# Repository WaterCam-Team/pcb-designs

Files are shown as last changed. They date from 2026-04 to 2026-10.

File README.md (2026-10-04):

# SU WaterCam PCB

Custom KiCad HAT for the **SU-WaterCam** project. Stacks on a Raspberry Pi 4B via a WittyPi 4 RTC/power-manager board, adding thermal imaging, LoRaWAN telemetry, IMU orientation, and environmental sensing.

**Software repo:** [mandeeps/SU-WaterCam](https://github.com/mandeeps/SU-WaterCam)  
**Schematic/pin map:** [PIN_MAP.md](PIN_MAP.md)

---

## Stack Order

Raspberry Pi 4B → WittyPi 4 (stacking header) → WaterCam HAT

---

## Components

| Reference | Part | Interface | Notes |
|---|---|---|---|
| U2 | Adafruit BNO055 STEMMA QT | I2C1 (0x28) | 9-DOF IMU; INT→GPIO20, RST→GPIO16 |
| U3 | Multitech MTDOT-915 | UART5 (GPIO12/13) | LoRaWAN; always-on 3.3 V from WittyPi J3 |
| U1 | Adafruit AHT20 | I2C1 (0x38) | Temp/humidity |
| J2 | FLIR Lepton Breakout v2 | SPI0 + I2C1 | 2×10 header; SPI for image data, I2C for CCI |
| J3 | WittyPi 4 P3 header | — | Taps always-on 3.3 V and SW pin for mDot |
| Q1 | MOSFET | — | mDot PB_1 pulls WittyPi SW low for remote wake |

---

## Power Domains

| Rail | Source | Powers |
|---|---|---|
| +3V3 (Pi) | Pi J1 pin 1 | AHT20, BNO055 breakout, I2C pull-ups R6/R7 |
| 5 V (Pi) | Pi J1 pin 2/4 | FLIR Lepton VIN (J2-P2) |
| 3.3 V (always-on) | WittyPi J3 pin 2 | mDot VDD, mDot NRESET pull-up — survives Pi shutdown |

---

## PCB Details

- **Layers:** 2 (F.Cu, B.Cu)
- **Signal traces:** 0.25 mm
- **Power traces:** 0.5 mm
- **Clearance:** 0.20 mm (default net class)

---

## PCB Images

- **Wiring/Layout Diagram**  
  Wiring/Layout Diagram of SU-WaterCam PCB

- **PCB Render**  
  3D Render of SU-WaterCam PCB

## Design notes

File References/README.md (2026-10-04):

# Reference documents

The design was checked against these vendor documents. They aren't committed
here because they are the vendors' copyright; download them from the vendor:

| Document | Source |
|---|---|
| AHT20 data sheet | Aosong (ASAIR) |
| Adafruit AHT20 temperature & humidity breakout guide | Adafruit Learning System |
| Adafruit 9-DOF orientation IMU fusion breakout (BNO085) guide | Adafruit Learning System |
| FLIR Lepton Breakout Board v2 schematic | GroupGets / Teledyne FLIR |
| Lepton Integration Series 302: SPI and I2C protocols | Teledyne FLIR |
| Lepton adaptor schematic | Teledyne FLIR |
| Quick start guide: Lepton and Raspberry Pi | GroupGets |
| IRLB8721PbF MOSFET data sheet | Infineon (International Rectifier) |
| Quectel EC25/EC21 GNSS AT commands manual v1.1 | Quectel |
| Witty Pi 4 user manual | UUGear |
| MultiTech mDot developer guide (S000612) | MultiTech |

`wiring_diagram.svg` in this folder is our own.

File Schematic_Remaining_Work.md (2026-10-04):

# WaterCam HAT — Schematic Remaining Work

**Board:** WaterCam_mDot_WittyPi_AHT_BNO_Lepton  
**Schematic:** `WaterCam_mDot_WittyPi_AHT_BNO_Lepton.kicad_sch` (KiCad 9)  
**Prepared:** 2026-05-10  
**Scope:** Schematic-only fixes. PCB layout work tracked separately.

---

## Status Summary

| # | Issue | Schematic Fix | Status |
|---|---|---|---|
| 7 | EEPROM artifacts (labels + wires) | Remove ID_SDA/ID_SCL labels and wires | ✅ Done |
| 9 | No I2C pull-up resistors | Add R6, R7 (4.7 kΩ each) | ✅ Done |
| 11 | Q1 MOSFET oversized (IRLB8721 TO-252) | Swap to 2N7002 SOT-23 | ✅ Done |
| 14 | Q1 gate resistor missing | Add R8 (100 Ω) in gate net | ✅ Done |
| 16 | mDot NRESET unconnected | Add 10 kΩ pull-up to 3.3 V | ✅ Done |
| 17 | J2-P18 PW_DWN_L not tied | Verify +3V3 tie; add if missing | ✅ Done |
| 8/15 | Decoupling caps missing | Add C1–C6 (100µF/100nF/10µF) | ✅ Done |
| ERC | +3V3 net power flag | Add #FLG04 (PWR_FLAG) on +3V3 | ✅ Done |

Issues #1–6, #10, #12, #13 are either fixed, N/A, or PCB-layout-only.

**Schematic complete. All issues resolved. Ready for ERC + PCB update.**

---

## Issue #7 — Remove EEPROM Artifacts

**Background:** U4 (CAT24C256 EEPROM) was added in an earlier session then deemed unnecessary (overlays loaded via config.txt). U4 was removed from the schematic but the schematic still has dangling ID_SDA/ID_SCL net labels and their connecting wires at J1 GPIO0 (Pi pin 27) and GPIO1 (Pi pin 28). These conflict with the no_connect marks already placed at the same points, causing ERC errors.

**Elements to remove:**
| Element | Location | Action |
|---|---|---|
| Label `ID_SDA` | (31.75, 60.96, 0°) | Delete |
| Label `ID_SCL` | (100.33, 60.96, 180°) | Delete |
| Wire J1-GPIO0 → label | (60.96, 60.96) → (31.75, 60.96) | Delete |
| Wire J1-GPIO1 → label | (73.66, 60.96) → (100.33, 60.96) | Delete |
| `no_connect` at label end | (31.75, 60.96) UUID `41ad66df-...` | Delete |
| `no_connect` at label end | (100.33, 60.96) UUID `bb504bb4-...` | Delete |

**Elements to add:**
| Element | Location | Reason |
|---|---|---|
| `no_connect` | (60.96, 60.96) | Mark J1 pin 27 (GPIO0/ID_SDA) as intentionally NC |
| `no_connect` | (73.66, 60.96) | Mark J1 pin 28 (GPIO1/ID_SCL) as intentionally NC |

**Verification:** After edit, ERC should show no error for J1 pins 27/28. Both should appear as clean no-connects in the netlist.

---

## Issue #9 — I2C Pull-Up Resistors (R6, R7)

**Background:** The I2C1 bus (GPIO2/SDA1, GPIO3/SCL1) has no board-level pull-ups. The Adafruit AHT20 and BNO055 breakout boards include their own 10 kΩ pull-ups, but having multiple boards in parallel on a shared bus weakens the effective pull-up strength. The Lepton CCI interface (I2C at 0x2A) requires pull-ups to be present. Adding 4.7 kΩ on the HAT provides a stable bus regardless of which breakouts are populated.

**Design:**
- R6: 4.7 kΩ, 0402, from GPIO2/SDA1 to +3.3 V
- R7: 4.7 kΩ, 0402, from GPIO3/SCL1 to +3.3 V

**Schematic approach:** Place R6 and R7 as vertical stubs branching off the SDA1 and SCL1 wires near J1. Each resistor connects between the signal net (via net label or T-junction on the existing wire) and a `power:+3V3` power symbol.

**Placement strategy:**
- Locate the SDA1 wire (y ≈ 30.48) and SCL1 wire (y ≈ 33.02) to the left of J1
- Add a junction on each wire at a free x-coordinate (e.g., x ≈ 20.32)
- Run a short vertical wire stub upward from each junction
- Place R6 / R7 vertically (90°) above the junction
- Connect top pin of each resistor to a `power:+3V3` symbol

**Net labels:** SDA1 net = `GPIO2{slash}SDA1`, SCL1 net = `GPIO3{slash}SCL1`

**New component definitions:**
```
R6: lib_id = Device:R_Small, value = "4.7kΩ", footprint = Resistor_SMD:R_0402_1005Metric
R7: lib_id = Device:R_Small, value = "4.7kΩ", footprint = Resistor_SMD:R_0402_1005Metric
```

**Note on +3.3 V source:** The Pi's 3.3 V rail appears at J1 pins 1 and 17 but is currently no-connect in the schematic (the HAT draws 3.3 V from the Pi only via breakout boards' own regulators). To add I2C pull-ups, add `power:+3V3` symbols connected directly to the J1 pin 1 (60.96, 27.94) and route pin 1 to a +3V3 power net. This also resolves the inconsistency where J1 pin 1 is no_connect while the schematic claims 3.3 V powers the breakouts.

**Alternative (simpler):** If the +3V3 net conflict is undesirable, use the `power:+5V` net and add a dedicated 3.3 V LDO (Issue #18) — but this is out of scope for schematic-only work. Use `power:+3V3` for now; verify J1 pin 1 drives it.

---

## Issue #11 — Q1 MOSFET Replacement (IRLB8721 → 2N7002)

**Background:** Q1 is an IRLB8721PBF (30 V / 62 A, TO-252 package) used as a small-signal switch to pull the WittyPi SW line LOW when the mDot asserts PB_1. This is severe overkill. The correct device is a 2N7002 (60 V / 300 mA, SOT-23) or BSS138.

**Gate drive:** mDot PB_1 = 3.3 V logic. Both 2N7002 (Vgs(th) ≈ 1.0–2.5 V) and BSS138 (Vgs(th) ≈ 0.8–1.5 V) fully saturate with 3.3 V gate drive.

**Schematic changes (properties only — no rewiring):**
| Property | Current | New |
|---|---|-----|
| `lib_id` | `Simulation_SPICE:NMOS` | `Transistor_FET:2N7002` |
| `Value` | `NMOS` | `2N7002` |
| `Footprint` | `IRLB8721PBF Model:TO254P1067X483X2057-3` | `Package_TO_SOT_SMD:SOT-23` |
| `Datasheet` | ngspice URL | `https://www.vishay.com/docs/70226/70226.pdf` |

**Pin mapping for 2N7002 in SOT-23:**
- Pin 1 = Gate (G)
- Pin 2 = Source (S)  
- Pin 3 = Drain (D)

**Note:** The `Transistor_FET:2N7002` KiCad symbol uses pin names G/D/S. Verify the lib_symbol pin orientation matches the existing wiring before saving. If the pin mapping differs from the current NMOS simulation symbol, the drain/source/gate connections must be reconciled.

**Alternative:** Keep the `Simulation_SPICE:NMOS` schematic symbol (generic N-MOSFET) and only update the footprint and value. This avoids a pin-mapping conflict. A BOM note can specify 2N7002/BSS138.

---

## Issue #14 — Q1 Gate Resistor (R8, 100 Ω)

**Background:** mDot PB_1 drives Q1 gate directly with only a 10 kΩ pull-down (R3). No series gate resistor exists. At 3.3 V / 10 kΩ, gate current is 330 µA, which is fine for steady state. The concern is ringing at turn-on/off: the LoRa module's GPIO transitions can excite the gate-source capacitance (Ciss ≈ 50–100 pF for 2N7002) causing ringing on the gate that may cause spurious switching.

**Fix:** Add R8 = 100 Ω in series between the mDot PB_1 signal and Q1 gate. The R3 10 kΩ pull-down remains connected at the Q1 gate side (after R8), which is correct — it provides DC bias when mDot is unpowered.

**Circuit topology:**
```
mDot PB_1 ── R8 (100Ω) ─┬─ Q1 Gate
                          │
                         R3 (10kΩ)
                          │
                         GND
```

**Schematic changes:**
1. Identify the gate wire segment (the wire running at y ≈ 172.72 from Q1 gate toward the mDot PB_1 side)
2. Break this wire at a point approximately 10–15 mm from Q1 gate (to leave room for R8 symbol)
3. Add R8 (`Device:R_Small`, value `100Ω`, footprint `Resistor_SMD:R_0402_1005Metric`) in the gap, oriented horizontally (0°)
4. Connect R8 pin 1 to the mDot-PB_1-side wire stub
5. Connect R8 pin 2 to the Q1 gate-side wire stub

**R3 stays:** The existing R3 (10 kΩ at position ~177.8, 161.29, vertical) is the gate pull-down. Its connection to the Q1 gate net is correct and unchanged.

---

## Issue #16 — mDot NRESET Pull-Up

**Background:** mDot NRESET (active-low, pin 5 of U3) is currently no_connect at (243.84, 81.28). Leaving NRESET floating can cause spurious resets if the line picks up noise. The mDot datasheet recommends tying NRESET HIGH via a 10 kΩ resistor to VDD (3.3 V) with an optional 100 nF capacitor to GND.

**Fix:** Add R9 = 10 kΩ pull-up from NRESET to 3.3 V (WittyPi always-on 3.3 V, same supply as mDot VDD).

**Schematic changes:**
1. Remove `no_connect` at (243.84, 81.28)
2. Add a short wire stub from (243.84, 81.28) going LEFT (decreasing x) to approximately (234.95, 81.28)
3. Place R9 (`Device:R_Small`, value `10kΩ`, footprint `Resistor_SMD:R_0402_1005Metric`) horizontally (0°) with pin 1 at (234.95, 81.28)
4. Add a wire from R9 pin 2 (left side) going left to approximately (228.6, 81.28)
5. Add a `power:+3V3` symbol at the end OR use the WittyPi J3-3V3 label to connect to the always-on 3.3 V supply

**Power domain note:** mDot VDD is already on WittyPi J3-3V3 (always-on). NRESET must also be on this rail — if tied to Pi 3.3 V (which goes off when WittyPi shuts the Pi), NRESET would assert LOW during Pi shutdown and hold the mDot in reset. Use WittyPi J3-3V3 for this pull-up.

**Schematic label:** The J3-3V3 wire chain already exists. Connect R9 top to the same net using a `power:+3V3` symbol OR a local wire to J3 pin 2 (at (231.14, 35.56)).

---

## Issue #17 — J2-P18 PW_DWN_L Verification

**Background:** Fix 5 was supposed to tie J2-P18 (Lepton PW_DWN_L) to +3.3 V so the Lepton is always powered. Verify this fix is actually present in the current schematic.

**Check:**
- J2-P18 position: even pin at (121.92, 128.27)
- Expected: wire from (121.92, 128.27) to a `power:+3V3` symbol (or at minimum, a wire to the +3V3 rail)
- Current state: `no_connect` found at (121.92, 128.27) — **Fix 5 may not be applied**

**Action:** If no_connect is the only thing at (121.92, 128.27):
1. Remove the `no_connect` at (121.92, 128.27)
2. Add a short wire from (121.92, 128.27) going LEFT to ~(113.03, 128.27)
3. Add `power:+3V3` symbol at (113.03, 128.27)
4. Add a 10 kΩ pull-up resistor between this +3V3 and the signal for cleaner design (optional; direct tie is acceptable per Issue #17 note in the main change doc)

---

## PCB Layout Work (Out of Scope for This Document)

These require the PCB editor (not the schematic):

| # | Action |
|---|---|
| 8/15 | Add decoupling caps C1–C6 (see WaterCam_PCB_Design_Changes_Required.md §8) |
| 12 | Verify stacking header J1 height (11–13 mm female socket) |
| 13 | Fix MTDOT footprint duplicate pad "24" |

All PCB changes should be deferred until schematic issues #7, #9, #11, #14, #16, #17 are resolved and the schematic passes ERC.

---

## KiCad Coordinate Reference

Key known positions in schematic space:

| Component | Position | Notes |
|---|---|---|
| J1 (Pi header) | (66.04, 50.8, 0°) | `Conn_02x20_Odd_Even`; left col x=60.96, right col x=73.66 |
| J2 (Lepton) | (129.54, 118.11, 0°, mirror y) | Even pins x=121.92, Odd pins x=134.62; y=107.95–130.81 |
| J3 (WittyPi P3) | (195.58, 57.15, 0°) | Pin 2 (3V3) at (231.14, 35.56) |
| U3 (mDot) | (274.32, 83.82, 90°, mirror x) | x_abs = 274.32 − ly_local; y_abs = 83.82 + lx_local |
| U2 (BNO055) | (153.67, 29.21, 180°) | x_abs = 153.67 − lx_local; y_abs = 29.21 + ly_local |
| Q1 (NMOS) | (82.55, 172.72, 0°) | Gate net wire runs at y=172.72 |
| R3 (10kΩ pull-down) | (177.8, 161.29, 90°) | Gate pull-down; keep in place |
| J1-GPIO0 pin | (60.96, 60.96) | Currently has wire+label "ID_SDA" (to be removed) |
| J1-GPIO1 pin | (73.66, 60.96) | Currently has wire+label "ID_SCL" (to be removed) |
| J1-GPIO2/SDA1 | (60.96, 30.48) | Wire goes left to label at (31.75, 30.48) |
| J1-GPIO3/SCL1 | (60.96, 33.02) | Wire goes left to label at (31.75, 33.02) |
| mDot NRESET | (243.84, 81.28) | Currently no_connect; add 10kΩ pull-up |
| J2-P18 PW_DWN_L | (121.92, 128.27) | Currently no_connect; should tie +3V3 |

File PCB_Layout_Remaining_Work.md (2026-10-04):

# WaterCam HAT — PCB Layout Remaining Work

**Schematic:** WaterCam_mDot_WittyPi_AHT_BNO_Lepton.kicad_sch — all schematic issues resolved  
**PCB file:** WaterCam_mDot_WittyPi_AHT_BNO_Lepton.kicad_pcb  
**Prepared:** 2026-05-10  

---

## Prerequisites Before Opening PCB Editor

1. **Run ERC** on the schematic (KiCad Schematic Editor → Inspect → Electrical Rules Checker).  
   Expected warnings:
   - `+3V3` net "Power pin not driven" — add PWR_FLAG (#FLG04) at any +3V3 node (e.g., (60.96, 27.94) alongside the +3V3 at J1 pin 1) to silence it.
   - Any remaining unconnected pin warnings from the no_connects should pass cleanly.

2. **Update PCB from Schematic** (KiCad PCB Editor → Tools → Update PCB from Schematic, or Schematic Editor → Tools → Update PCB from Schematic).  
   This syncs all schematic changes into the PCB netlist:
   - R6, R7 (new I2C pull-ups) will appear as unplaced footprints
   - R8, R9 (gate resistor + nReset pull-up) will appear if not already placed
   - Q1 footprint change (IRLB8721 TO-252 → 2N7002 SOT-23) will need re-placement
   - +3V3 power net will be defined

---

## Issue #8 / #15 — Decoupling Capacitors C1–C6

**Why:** The mDot generates LoRa TX current spikes up to 600 mA peak on a 3.3V always-on rail that also powers WittyPi's MCU/RTC. Without local bulk capacitance, these spikes propagate back onto the WittyPi P3-3V3 rail and may cause the RTC to reset or glitch. The Lepton and I2C sensors also benefit from local bypass caps.

**Schematic step first:** Add C1–C6 to the schematic before updating the PCB.

| Ref | Value | Type | Location in schematic | Purpose |
|-----|---|---|---|---|
| C1 | 100 µF, 6.3V | Electrolytic (radial or SMD) | mDot VDD (179.07, 83.82) | mDot bulk — absorbs LoRa TX spikes |
| C2 | 100 nF, 10V | Ceramic 0402 | mDot VDD (179.07, 83.82) | mDot bypass |
| C3 | 100 nF, 10V | Ceramic 0402 | AHT20 VDD (U1 pin VDD) | AHT20 bypass |
| C4 | 10 µF, 10V | Ceramic 0402 or 0603 | AHT20 VDD | AHT20 bulk |
| C5 | 100 nF, 10V | Ceramic 0402 | BNO055 VIN (U2 pin VDD) | BNO055 bypass |
| C6 | 100 nF, 10V | Ceramic 0402 | J2-P2 (Lepton VIN) | Lepton bypass |

**Schematic additions for each cap:**
- `lib_id`: `Device:C_Small` (0402 ceramic) or `Device:C` (electrolytic C1)
- Value and footprint per table above
- One pin to the relevant VDD net (via junction on existing wire or net label)
- Other pin to `power:GND`

**PCB placement rules:**
- C1 (100 µF bulk): within 8 mm of mDot U3 VDD pad (castellated pad on mDot left edge)
- C2 (100 nF bypass): within 3 mm of mDot U3 VDD pad, closer than C1
- C3, C4: within 5 mm of U1 (AHT20) VDD pin
- C5: within 5 mm of U2 (BNO055) VIN pin
- C6: within 5 mm of J2 (Lepton) P2 pin (5V power pin)
- Orient all caps so GND pad faces the nearest GND pour or via

---

## Issue #12 — Stacking Header J1 Height

**Why:** The WittyPi 4 stacks on the Pi 4B and its tallest components sit ~12 mm above the WittyPi PCB surface. The HAT PCB must sit above these components, so J1 must be a tall female stacking socket.

**Recommended part:** 2×20 female tall stacking header, 13.5 mm body height (e.g., Adafruit 1979 or equivalent). This gives ~2 mm clearance over WittyPi components and mates over the WittyPi's protruding male header pins.

**Schematic/BOM action only — no PCB layout change:**
- J1 footprint in PCB file should remain as `Connector_PinHeader_2.54mm:PinHeader_2x20_P2.54mm_Vertical` (through-hole, 2×20)
- Add a BOM note: J1 = tall stacking female socket, 2×20, 13.5 mm or 11 mm height
- Verify physical clearance by measuring WittyPi component heights before ordering

**Check:** Does the PCB have adequate standoff hole placement (M2.5 mounting holes at Pi corner positions)? Verify all four mounting holes are present and unobstructed.

---

## Issue #13 — MTDOT Footprint Duplicate Pad "24"

**Why:** The mDot MTDOT-915 footprint has two pads both numbered "24." KiCad assigns both pads to the same net, which means one pad may be unrouted or mis-netted. Manufacturing may flag this as a DRC error.

**Investigation steps:**
1. Open `WaterCam_mDot_WittyPi_AHT_BNO_Lepton.kicad_pcb` in KiCad PCB editor
2. Select U3 (mDot footprint) → Edit Footprint → inspect pad numbers
3. The mDot MTDOT-915 physical package: 20 castellated edge pads (10 per side, numbered 1–20) + bottom RF ground pad

**MTDOT-915 correct pad numbering** (from mDot datasheet, pads numbered left-right, top row first):
- Top edge (pads 1–10 odd, or sequential — verify from datasheet)
- Bottom edge (pads 11–20)
- RF pad: "RF" or pad 21
- GND pad (bottom center): pad 22 or "GND"

**Action:**
- Identify which two pads share number "24" in the footprint
- Determine which pad is correctly "24" from the datasheet pad map
- Renumber the other pad to its correct number
- Update the net assignment in the PCB if the corrected pad was on the wrong net
- Run DRC after fix to confirm no pad errors remain

**Note:** This is a PCB-file-only fix. The schematic U3 symbol uses pin numbers mapped by the mDot lib_symbol; changing footprint pad numbers does not change schematic pin assignments as long as the pin→pad mapping is consistent.

---

## Order of Operations

1. Add ERC PWR_FLAG for +3V3 net in schematic (optional — silences ERC warning)
2. Add C1–C6 to schematic (Device:C_Small / Device:C, connected to correct nets)
3. Run ERC — should pass cleanly
4. Open PCB editor → Tools → Update PCB from Schematic
5. Resolve any footprint changes (Q1 SOT-23, R6, R7, R8, R9, C1–C6 appear as new)
6. Place new components:
   - Q1 (SOT-23) near R3 / J3 SW signal area
   - R6, R7 near J1 (I2C lines) — small footprints, place on free copper area
   - R8 (0402) inline on gate trace between R3 and mDot PB_1 pad
   - R9 (0402) between mDot NRESET pad and 3V3 supply
   - C1–C6 per placement rules above
7. Fix duplicate pad #24 on U3 (mDot footprint)
8. Verify J1 header footprint is through-hole 2×20 — no PCB change, BOM note only
9. Run DRC — fix any clearance or unrouted net errors
10. Generate Gerbers

---

## Component Reference Summary (Post-Schematic)

| Ref | Part | Footprint | Value | Status |
|-----|---|---|---|---|
| R3 | Pull-down | Resistor_THT:R_Axial... | 10 kΩ | Existing — keep |
| R6 | SDA1 pull-up | Resistor_SMD:R_0402_1005Metric | 4.7 kΩ | New — needs placement |
| R7 | SCL1 pull-up | Resistor_SMD:R_0402_1005Metric | 4.7 kΩ | New — needs placement |
| R8 | Q1 gate resistor | Resistor_SMD:R_0402_1005Metric | 100 Ω | New — needs placement |
| R9 | mDot NRESET pull-up | Resistor_SMD:R_0402_1005Metric | 10 kΩ | New — needs placement |
| Q1 | Remote-wake MOSFET | Package_TO_SOT_SMD:SOT-23 | 2N7002 | Changed footprint — re-place |
| C1 | mDot bulk cap | (TBD — electrolytic or large SMD) | 100 µF | New |
| C2 | mDot bypass | Capacitor_SMD:C_0402_1005Metric | 100 nF | New |
| C3 | AHT20 bypass | Capacitor_SMD:C_0402_1005Metric | 100 nF | New |
| C4 | AHT20 bulk | Capacitor_SMD:C_0402_1005Metric or 0603 | 10 µF | New |
| C5 | BNO055 bypass | Capacitor_SMD:C_0402_1005Metric | 100 nF | New |
| C6 | Lepton bypass | Capacitor_SMD:C_0402_1005Metric | 100 nF | New |

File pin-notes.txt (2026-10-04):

WaterCam HAT — Connection List

Pi J1 GPIO (used pins only)

┌─────┬────────┬─────────────────────────────────────────────────┐
│ Pin │  BCM   │                   Connection                    │
├─────┼────────┼─────────────────────────────────────────────────┤
│ 1   │ —      │ 3.3V → BNO055 VIN, AHT20 VIN                    │
├─────┼────────┼─────────────────────────────────────────────────┤
│ 2   │ —      │ 5V → Lepton J2-P2 (VIN)                         │
├─────┼────────┼─────────────────────────────────────────────────┤
│ 3   │ GPIO2  │ I2C1 SDA → Lepton P5, BNO055 SDA, AHT20 SDA     │
├─────┼────────┼─────────────────────────────────────────────────┤
│ 5   │ GPIO3  │ I2C1 SCL → Lepton P8, BNO055 SCL, AHT20 SCL     │
├─────┼────────┼─────────────────────────────────────────────────┤
│ 7   │ GPIO4  │ ⛔ WittyPi MCU — NC on HAT                      │
├─────┼────────┼─────────────────────────────────────────────────┤
│ 11  │ GPIO17 │ ⛔ WittyPi SYS_UP — NC on HAT                   │
├─────┼────────┼─────────────────────────────────────────────────┤
│ 18  │ GPIO24 │ — free (VSYNC unused by software)               │
├─────┼────────┼─────────────────────────────────────────────────┤
│ 19  │ GPIO10 │ Lepton SPI MOSI (J2-P9)                         │
├─────┼────────┼─────────────────────────────────────────────────┤
│ 21  │ GPIO9  │ Lepton SPI MISO (J2-P12)                        │
├─────┼────────┼─────────────────────────────────────────────────┤
│ 23  │ GPIO11 │ Lepton SPI CLK (J2-P7)                          │
├─────┼────────┼─────────────────────────────────────────────────┤
│ 24  │ GPIO8  │ Lepton SPI CS (J2-P10)                          │
├─────┼────────┼─────────────────────────────────────────────────┤
│ 29  │ GPIO5  │ mDot PA_6 + manual button (button pulls to GND) │
├─────┼────────┼─────────────────────────────────────────────────┤
│ 31  │ GPIO6  │ Lepton RESET_L (J2-P17)                         │
├─────┼────────┼─────────────────────────────────────────────────┤
│ 32  │ GPIO12 │ UART5 TX → mDot PA_3                            │
├─────┼────────┼─────────────────────────────────────────────────┤
│ 33  │ GPIO13 │ UART5 RX ← mDot PA_2                            │
├─────┼────────┼─────────────────────────────────────────────────┤
│ 36  │ GPIO16 │ BNO055 RST (hold HIGH; pulse LOW to reset)      │
├─────┼────────┼─────────────────────────────────────────────────┤
│ 38  │ GPIO20 │ BNO055 INT (input, pull-up)                     │
├─────┼────────┼─────────────────────────────────────────────────┤
│ 40  │ GPIO21 │ IR-CUT filter (external — not on PCB)           │
└─────┴────────┴─────────────────────────────────────────────────┘

---
FLIR Lepton Breakout Board v2.0 (J2) — Teledyne FLIR, 2x10 header

Pinout verified against References/FLIR_Lepton_Breakout_Board_V2_Schematic-16912.pdf.
Do NOT renumber from other Lepton breakout variants — their J2 numbering differs.

┌────────────┬─────────────┬───────────────────────────────┐
│   J2 Pin   │   Signal    │          Connects To          │
├────────────┼─────────────┼───────────────────────────────┤
│ P1         │ GND         │ GND                           │
├────────────┼─────────────┼───────────────────────────────┤
│ P2         │ VIN (3-5V)  │ Pi 5V                         │
├────────────┼─────────────┼───────────────────────────────┤
│ P3         │ VPROG       │ NC                            │
├────────────┼─────────────┼───────────────────────────────┤
│ P4         │ VCC28 out   │ NC (breakout 2.8V regulator)  │
├────────────┼─────────────┼───────────────────────────────┤
│ P5         │ SDA         │ GPIO2 (I2C1 SDA)              │
├────────────┼─────────────┼───────────────────────────────┤
│ P6         │ reserved    │ NC                            │
├────────────┼─────────────┼───────────────────────────────┤
│ P7         │ SPI CLK     │ GPIO11                        │
├────────────┼─────────────┼───────────────────────────────┤
│ P8         │ SCL         │ GPIO3 (I2C1 SCL)              │
├────────────┼─────────────┼───────────────────────────────┤
│ P9         │ SPI MOSI    │ GPIO10                        │
├────────────┼─────────────┼───────────────────────────────┤
│ P10        │ SPI CS      │ GPIO8 (SPI0.CE0)              │
├────────────┼─────────────┼───────────────────────────────┤
│ P11        │ GPIO0       │ NC                            │
├────────────┼─────────────┼───────────────────────────────┤
│ P12        │ SPI MISO    │ GPIO9                         │
├────────────┼─────────────┼───────────────────────────────┤
│ P13        │ GPIO2       │ NC                            │
├────────────┼─────────────┼───────────────────────────────┤
│ P14        │ GPIO1       │ NC                            │
├────────────┼─────────────┼───────────────────────────────┤
│ P15        │ GPIO3/VSYNC │ NC — must NOT go to GPIO17    │
│            │             │ (WittyPi SYS_UP); VSYNC is    │
│            │             │ unused by SU-WaterCam         │
├────────────┼─────────────┼───────────────────────────────┤
│ P16        │ VCC12 out   │ NC (breakout 1.2V regulator)  │
├────────────┼─────────────┼───────────────────────────────┤
│ P17        │ RESET_L     │ GPIO6 (active LOW)            │
├────────────┼─────────────┼───────────────────────────────┤
│ P18        │ MASTER_CLK  │ NC — driven by breakout 25MHz │
│            │             │ oscillator Y1. NEVER tie to a │
│            │             │ supply rail.                  │
├────────────┼─────────────┼───────────────────────────────┤
│ P19        │ GND         │ GND (same net as P1)          │
├────────────┼─────────────┼───────────────────────────────┤
│ P20        │ PW_DWN_L    │ NC — pulled up on breakout    │
│            │             │ via J6/J7                     │
└────────────┴─────────────┴───────────────────────────────┘

---
BNO055 STEMMA QT (U2)

┌───────────────┬─────────────────────────────┐
│      Pin      │         Connects To         │
├───────────────┼─────────────────────────────┤
│ VIN           │ Pi 3.3V                     │
├───────────────┼─────────────────────────────┤
│ GND           │ GND                         │
├───────────────┼─────────────────────────────┤
│ SDA           │ GPIO2 (I2C1 SDA)            │
├───────────────┼─────────────────────────────┤
│ SCL           │ GPIO3 (I2C1 SCL)            │
├───────────────┼─────────────────────────────┤
│ RST           │ GPIO16                      │
├───────────────┼─────────────────────────────┤
│ INT           │ GPIO20                      │
├───────────────┼─────────────────────────────┤
│ PS0, PS1, ADR │ NC (pulled GND on breakout) │
└───────────────┴─────────────────────────────┘

---
AHT20 (U1)

┌─────┬──────────────────┐
│ Pin │   Connects To    │
├─────┼──────────────────┤
│ VIN │ Pi 3.3V          │
├─────┼──────────────────┤
│ GND │ GND              │
├─────┼──────────────────┤
│ SDA │ GPIO2 (I2C1 SDA) │
├─────┼──────────────────┤
│ SCL │ GPIO3 (I2C1 SCL) │
└─────┴──────────────────┘

---
Multitech mDot (U3)

┌─────────────────┬───────────────────────────────────┐
│       Pin       │            Connects To            │
├─────────────────┼───────────────────────────────────┤
│ VDD (pad 1)     │ WittyPi J3 pin 2 (always-on 3.3V) │
├─────────────────┼───────────────────────────────────┤
│ GND (pad 10)    │ WittyPi J3 pin 7                  │
├─────────────────┼───────────────────────────────────┤
│ PA_2 TX (pad 2) │ GPIO13 / RXD5                     │
├─────────────────┼───────────────────────────────────┤
│ PA_3 RX (pad 3) │ GPIO12 / TXD5                     │
├─────────────────┼───────────────────────────────────┤
│ PA_6 (pad 6)    │ GPIO5                             │
├─────────────────┼───────────────────────────────────┤
│ PB_1 (pad 19)   │ Q1 gate (+ R3 pull-down)          │
└─────────────────┴───────────────────────────────────┘

---
WittyPi 4 P3 Header (J3)

┌─────────┬────────┬─────────────────────┐
│ J3 Pin  │ Signal │     Connects To     │
├─────────┼────────┼─────────────────────┤
│ 2       │ 3V3    │ mDot VDD            │
├─────────┼────────┼─────────────────────┤
│ 5       │ SW     │ Q1 drain            │
├─────────┼────────┼─────────────────────┤
│ 7       │ GND    │ mDot GND, Q1 source │
├─────────┼────────┼─────────────────────┤
│ 1,3,4,6 │ —      │ NC                  │
└─────────┴────────┴─────────────────────┘

---
Q1 Remote-Start Circuit

Part: BSS138 (N-channel MOSFET, SOT-23, 50 V / 0.22 A, Vgs(th) 0.8-1.5 V)
Net:  /WP_SW  (Q1 drain <-> WittyPi J3 pin 5)

┌────────┬──────────────┬──────────────────────────────┐
│  Node  │  SOT-23 pad  │         Connects To          │
├────────┼──────────────┼──────────────────────────────┤
│ Gate   │ 1            │ R8 (100 Ω) from mDot PB_1;   │
│        │              │ R3 (10 kΩ) pulldown to GND   │
├────────┼──────────────┼──────────────────────────────┤
│ Source │ 2            │ GND                          │
├────────┼──────────────┼──────────────────────────────┤
│ Drain  │ 3            │ WittyPi J3 SW (pin 5)        │
└────────┴──────────────┴──────────────────────────────┘

⚠ Pad order is G-S-D (pads 1-2-3), the standard SOT-23 MOSFET pinout. Use a symbol
based on Q_NMOS_GSD (e.g. Transistor_FET:BSS138). Do NOT use Simulation_SPICE:NMOS -
its pins are numbered D=1, G=2, S=3, which silently mis-pins the part on the PCB.
The mDot drives the gate at 3.3 V, so the FET must be logic-level.

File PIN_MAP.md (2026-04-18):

# WaterCam HAT — GPIO & Connector Pin Map

**Board:** WaterCam_mDot_WittyPi_AHT_BNO_Lepton  
**Target SBC:** Raspberry Pi 4B  
**Stack order (bottom→top):** Raspberry Pi 4B → WittyPi 4 (via stacking header) → WaterCam HAT  
**Schematic:** `WaterCam_mDot_WittyPi_AHT_BNO_Lepton.kicad_sch`  
**Software repo:** [mandeeps/SU-WaterCam](https://github.com/mandeeps/SU-WaterCam)

---

## Legend

| Symbol | Meaning |
|---|---|
| ⛔ RESERVED | Pin claimed by WittyPi 4 hardware — do not connect to anything else |
| ⚠️ SHARED | Pin shared by multiple peripherals |
| — | Unassigned / not connected to any HAT signal |

---

## Raspberry Pi 40-Pin GPIO Header (J1)

Physical pin numbers follow the standard Raspberry Pi 40-pin header (odd column = pins 1–39, even column = pins 2–40, top to bottom).  
BCM numbering used throughout software (e.g., `gpiozero`, `libgpiod`, `/boot/config.txt`).

| Phys | BCM | Alt Function | Assigned To | Peripheral | Notes |
|---|-----|---|---|---|---|
| 1 | — | 3.3 V | VCC rail | AHT20, BNO055 breakouts | Pi 3.3 V; cut when WittyPi shuts Pi off |
| 2 | — | 5 V | VCC rail | FLIR Lepton VIN (J2-P2) | |
| 3 | GPIO2 | SDA1 (I2C1) | I2C bus SDA | FLIR Lepton CCI, AHT20, BNO055, WittyPi RTC | Bus shared; see I2C address map below |
| 4 | — | 5 V | — | — | |
| 5 | GPIO3 | SCL1 (I2C1) | I2C bus SCL | FLIR Lepton CCI, AHT20, BNO055, WittyPi RTC | Bus shared |
| 6 | — | GND | GND | — | |
| 7 | GPIO4 | GPCLK0 | ⛔ RESERVED | WittyPi 4 | WittyPi MCU communication — do not use |
| 8 | GPIO14 | TXD0 (UART0) | NC | — | No-connect in schematic; UART5 used for mDot instead |
| 9 | — | GND | GND | — | |
| 10 | GPIO15 | RXD0 (UART0) | NC | — | No-connect in schematic |
| 11 | GPIO17 | — | ⛔ RESERVED | WittyPi 4 SYS_UP | **Must never be driven by HAT.** WittyPi monitors this line — LOW → WittyPi cuts power, causing boot loop. See [Design Notes](#design-notes). |
| 12 | GPIO18 | PCM.CLK / PWM0 | — | — | |
| 13 | GPIO27 | — | — | — | |
| 14 | — | GND | GND | — | |
| 15 | GPIO22 | — | — | — | |
| 16 | GPIO23 | — | — | — | |
| 17 | — | 3.3 V | — | — | |
| 18 | GPIO24 | — | FLIR Lepton GPIO2 / VSYNC | FLIR Lepton J2-P15 | Rerouted from GPIO17 in v7 schematic fix |
| 19 | GPIO10 | SPI0.MOSI | SPI0 MOSI | FLIR Lepton J2-P5 | |
| 20 | — | GND | GND | — | |
| 21 | GPIO9 | SPI0.MISO | SPI0 MISO | FLIR Lepton J2-P12 | |
| 22 | GPIO25 | — | — | — | |
| 23 | GPIO11 | SPI0.SCLK | SPI0 Clock | FLIR Lepton J2-P3 | |
| 24 | GPIO8 | SPI0.CE0 | SPI0 Chip Select | FLIR Lepton J2-P8 | |
| 25 | — | GND | GND | — | |
| 26 | GPIO7 | SPI0.CE1 | — | — | |
| 27 | GPIO0 | ID_SDA (I2C0) | NC | — | No EEPROM fitted; overlays loaded via config.txt |
| 28 | GPIO1 | ID_SCL (I2C0) | NC | — | No EEPROM fitted |
| 29 | GPIO5 | — | ⚠️ SHARED: mDot PA_6 + manual capture button | mDot remote-start input + pushbutton | Pi drives HIGH when running (PA_6 reads this); button also pulls to GND for manual capture |
| 30 | — | GND | GND | — | |
| 31 | GPIO6 | — | FLIR Lepton RESET_L | FLIR Lepton J2-P17 | HIGH by default; pulse LOW to reset Lepton; used by `lepton_reset.py` |
| 32 | GPIO12 | TXD5 (UART5) | UART5 TX → mDot RX | mDot PA_3 | Enabled via `dtoverlay=uart5`; /dev/ttyAMA5 |
| 33 | GPIO13 | RXD5 (UART5) | UART5 RX ← mDot TX | mDot PA_2 | Enabled via `dtoverlay=uart5`; /dev/ttyAMA5 |
| 34 | — | GND | GND | — | |
| 35 | GPIO19 | PCM.FS / SPI1.MISO | — | — | |
| 36 | GPIO16 | — | BNO055 RST | BNO055 breakout U2 | Active-low reset; hold HIGH normally; pulse LOW to reset IMU |
| 37 | GPIO26 | — | — | — | |
| 38 | GPIO20 | PCM.DIN / SPI1.MOSI | BNO055 INT | BNO055 breakout U2 | Interrupt-driven IMU reads; active-low output from BNO055 |
| 39 | — | GND | GND | — | |
| 40 | GPIO21 | PCM.DOUT | IR-CUT filter control | NIR optical camera | Driven by `take_nir_photos.py`; HIGH/LOW toggles IR-CUT filter |

---

## FLIR Lepton Breakout Board v2 — Connector J2 (2×10, 20-pin)

J2 is a 2×10 male header on the HAT mating to the FLIR Lepton Breakout Board v2.  
Pin convention: odd pins (P1, P3, …, P19) on one row; even pins (P2, P4, …, P20) on the other.  
Reference: [FLIR Lepton Raspberry Pi Guide](https://github.com/FLIR/Lepton/blob/main/docs/RaspberryPiGuide.md)

| J2 Pin | Breakout Board Signal | Pi BCM | Pi Physical | Notes |
|---|---|---|---|---|
| P1 | SDA (CCI / I2C) | GPIO2 | 3 | I2C1 SDA; shared with AHT20 and BNO055 |
| P2 | VIN (+5 V) | — | 2 or 4 | Lepton core power |
| P3 | SPI CLK | GPIO11 | 23 | SPI0.SCLK — Lepton SPI clock (not I2C SCL) |
| P4 | NC | — | — | |
| P5 | MOSI | GPIO10 | 19 | SPI0 MOSI |
| P6 | NC (GND) | — | — | |
| P7 | NC (GND) | — | — | Internally tied to Lepton ground plane |
| P8 | CS (SPI chip select) | GPIO8 | 24 | SPI0.CE0 |
| P9 | NC (GND) | — | — | |
| P10 | NC | — | — | |
| P11 | NC | — | — | |
| P12 | MISO | GPIO9 | 21 | SPI0 MISO |
| P13 | NC | — | — | |
| P14 | NC | — | — | |
| P15 | GPIO2 / VSYNC | GPIO24 | 18 | Lepton frame-sync output; was GPIO17 in v6 — **fixed** |
| P16 | VPROG | NC | — | Programming voltage — not used |
| P17 | RESET_L | GPIO6 | 31 | Active-low reset; GPIO6 is HIGH by default; script pulses LOW |
| P18 | PW_DWN_L | +3.3 V direct | — | Tied HIGH → Lepton always powered; no software power-down |
| P19 | SCL (CCI / I2C) | GPIO3 | 5 | I2C1 SCL; shared with AHT20 and BNO055 |
| P20 | NC | — | — | |

> **I2C note:** P1 and P19 connect to the shared I2C1 bus. Use Y-splitter cables when wiring the breakout board directly (pre-HAT assembly). The HAT PCB handles this internally.

---

## Multitech mDot LoRaWAN Module (U3, MTDOT-915) — Connector J1 on mDot

The mDot is powered from the WittyPi 4 P3 auxiliary header (J3), **not** from the Pi's 3.3 V rail, so it stays alive while the Pi is off (required for LoRa receive and remote-start functionality).  
UART interface: `dtoverlay=uart5` in `/boot/config.txt`; serial port `/dev/ttyAMA5`; 115200 8N1.

| mDot Pin | mDot Signal | Connected To | Notes |
|---|---|---|---|
| 1 | VDD | J3 Pin 2 (WittyPi 3.3 V always-on) | **Not** Pi 3.3 V — survives Pi shutdown |
| 2 | PA_2 (UART TX) | GPIO13 / RXD5 (Pi pin 33) | mDot transmits → Pi receives |
| 3 | PA_3 (UART RX) | GPIO12 / TXD5 (Pi pin 32) | mDot receives ← Pi transmits |
| 10 | GND | J3 Pin 7 (WittyPi GND) | |
| PA_6 | Digital input | GPIO5 (Pi pin 29) | Pi drives HIGH when running; mDot reads to confirm Pi state |
| PB_1 | Digital output | Q1 MOSFET gate + R3 pull-down | mDot drives HIGH to trigger remote start via MOSFET |

**Remote-start circuit:**  
`mDot PB_1` → Q1 gate (10 kΩ pull-down R3 to GND) → Q1 drain → `WittyPi J3-SW` (pin 5). When mDot asserts PB_1 HIGH via LoRa command, Q1 pulls the WittyPi switch pin LOW, waking the Pi.

---

## Adafruit BNO055 STEMMA QT Breakout (U2, 10-pin header)

BNO055 is an Adafruit breakout board connected via a 10-pin 0.1" header. PS0, PS1, and ADR are pulled to GND by resistors on the breakout board (I2C mode, address 0x28 by default); they need no connections from the HAT.

| Breakout Pin | Signal | Connected To | Notes |
|---|---|---|---|
| VIN | Power in | Pi 3.3 V (J1 pin 1) | Onboard regulator; breakout accepts 3.3–5 V |
| GND | Ground | GND | |
| SDA | I2C1 SDA | GPIO2 (J1 pin 3) | Shared I2C1 bus |
| SCL | I2C1 SCL | GPIO3 (J1 pin 5) | Shared I2C1 bus |
| RST | Reset (active low) | GPIO16 (J1 pin 36) | Pi drives HIGH normally; pulse LOW to reset |
| INT | Interrupt (active low) | GPIO20 (J1 pin 38) | Configure Pi GPIO as input with pull-up |
| PS0 | Protocol select | NC | Pulled to GND on breakout (I2C mode) |
| PS1 | Protocol select | NC | Pulled to GND on breakout (I2C mode) |
| ADR | Address select | NC | Pulled to GND on breakout (I2C addr 0x28) |
| 3V3 | Regulated out | NC | 3.3 V output from breakout regulator; not used |

---

## Adafruit AHT20 Breakout (U1, 4-pin STEMMA QT / header)

AHT20 is a temperature and humidity sensor on a breakout board. Connected via I2C1.

| Breakout Pin | Signal | Connected To | Notes |
|---|---|---|---|
| VIN | Power in | Pi 3.3 V (J1 pin 1) | |
| GND | Ground | GND | |
| SDA | I2C1 SDA | GPIO2 (J1 pin 3) | Shared I2C1 bus |
| SCL | I2C1 SCL | GPIO3 (J1 pin 5) | Shared I2C1 bus |

---

## WittyPi 4 P3 Auxiliary Header (J3 on HAT, 7-pin)

The WittyPi 4 exposes a 7-pin P3 header. The HAT connects to it to draw always-on 3.3 V for the mDot.

| J3 Pin | WittyPi Signal | HAT Connection | Notes |
|---|---|---|---|
| 1 | VOUT | NC | |
| 2 | 3V3 | mDot VDD (U3 pin 1) | Always-on; active even when Pi is off |
| 3 | LED | NC | |
| 4 | ALM | NC | |
| 5 | SW | Q1 Drain | MOSFET switches this to GND for remote start |
| 6 | CATH | NC | |
| 7 | GND | mDot GND + Q1 Source | Common ground for mDot and remote-start circuit |

---

## I2C Device Address Map (I2C1, GPIO2/GPIO3)

All addresses are 7-bit. No conflicts.

| Address | Device | Component | Notes |
|---|---|---|---|
| 0x2A | FLIR Lepton CCI | Lepton 3.5 | Camera Command Interface; requires I2C for configuration |
| 0x38 | AHT20 | Temp/humidity sensor | Fixed address; no configurable bits |
| 0x28 or 0x29 | BNO055 | 9-DOF IMU (U2) | Address set by ADDR pin; ADDR=GND → 0x28 (breakout default) |
| 0x48 | LM75B | On-board WittyPi 4 temperature sensor | WittyPi internal component |
| 0x51 | PCF85063A | WittyPi 4 RTC | WittyPi internal component |

### I2C0 (GPIO0/GPIO1)

Not used. No EEPROM fitted. Device-tree overlays loaded manually via `/boot/firmware/config.txt`.

---

## Software / Kernel Configuration

Add the following to `/boot/firmware/config.txt` (Bookworm path; `/boot/config.txt` on older releases):

```ini
# UART5 for mDot LoRa module (GPIO12=TX, GPIO13=RX)
enable_uart=1
dtoverlay=uart5

# I2C clock stretching — enable if BNO055 causes I2C errors
# dtparam=i2c_arm_baudrate=10000

# FLIR Lepton SPI buffer size (add to /boot/cmdline.txt, not config.txt)
# spidev.bufsiz=131072
```

Serial port for mDot: `/dev/ttyAMA5` — use `tio /dev/ttyAMA5` at 115200 baud.

**BNO055 GPIO setup (add to boot script or `/etc/rc.local`):**

```bash
# Hold BNO055 out of reset (GPIO16 must be HIGH before I2C init)
raspi-gpio set 16 op dh

# Optional: configure BNO055 INT as input with pull-up
raspi-gpio set 20 ip pu
```

Or with `gpiozero`:
```python
from gpiozero import OutputDevice, Button
bno_rst = OutputDevice(16, initial_value=True)   # HIGH = not in reset
bno_int = Button(20, pull_up=True)               # active-low interrupt
```

---

## Design Notes

### GPIO17 — WittyPi 4 SYS_UP (CRITICAL)

GPIO17 (Pi physical pin 11) is monitored by the WittyPi 4 to determine whether the Raspberry Pi OS is running. The Pi drives this line HIGH when it is up. **If any peripheral drives GPIO17 LOW** — even briefly during initialization — the WittyPi will interpret it as a shutdown event and cut power, causing a boot loop or preventing boot entirely.

**v6.0 failure:** The Lepton Breakout Board J2-P15 (a GPIO output from the Lepton) was routed to GPIO17. Once the Lepton initialized and asserted P15, it pulled GPIO17 LOW → WittyPi cut power. **Fixed in current schematic:** J2-P15 is now routed to GPIO24 (pin 18), which is otherwise unallocated.

GPIO17 has **no connection** on the HAT PCB and must remain that way.

### GPIO4 — WittyPi 4 Communication

GPIO4 (Pi physical pin 7) is used by WittyPi 4 hardware for MCU communication. Do not assign to other purposes.

### J2-P1 — SDA, Not GND (v6.0 Fixed)

In v6.0, J2-P1 was wired to GND instead of SDA. GPIO2 has a 47 kΩ internal pull-up that is active from reset. Shorting it to GND through the Lepton connector permanently kills I2C1, preventing HAT EEPROM reads and WittyPi RTC communication.

### J2-P8 — SPI CS, Not I2C SCL (v6.0 Fixed)

In v6.0, J2-P8 (Lepton SPI CS) was wired to GPIO3/SCL1 instead of GPIO8/SPI0.CE0. Every SPI transaction would assert CS LOW → pull SCL LOW → freeze the I2C bus mid-transaction.

### BNO055/BNO085 INT and RST Pins

INT is connected to GPIO20 (pin 38) and RST to GPIO16 (pin 36). INT is active-low output from the BNO055; configure as input with pull-up for interrupt-driven IMU reads. RST is active-low input to the BNO055; hold HIGH normally and pulse LOW to reset. (Design issue #10 resolved.)

### mDot VSYNC / SPI note

The Lepton VSYNC signal (J2-P15, now GPIO24) is wired but not currently used by the capture software. The `lepton.c` / `capture.c` tools use SPI polling rather than VSYNC interrupts.

### Manual Capture Button

A pushbutton between GPIO5 (pin 29) and GND is supported by `button-service-gpiozero.py`. GPIO5 is also the line the mDot reads (PA_6) to detect that the Pi is powered on. Brief LOW pulses from button presses are transient and acceptable; the mDot PA_6 input is not time-critical.

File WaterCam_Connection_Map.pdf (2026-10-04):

## WaterCam PCB HAT - Connection Map

This document shows every electrical connection on the WaterCam custom PCB, written so you can see at a glance what’s connected to what.
Reading the arrows: A --> B means A is electrically connected to B. If multiple things are tied together, they appear on the right of the arrow separated by commas.
Components on the board:
Name | What it is
Pi | Raspberry Pi 4B GPIO header (40 pins, mates with the WittyPi underneath)
WittyPi | WittyPi 4 power management module (sits between Pi and our hat)
AHT20 | Adafruit temperature/humidity sensor breakout
BNO055 | Adafruit 9-axis IMU breakout
FLIR Lepton | Thermal camera socket
MTDOT | MultiTech LoRa radio module
MOSFET | IRLB8721PBF NMOS transistor (acts as a switch for the wake signal)
resistor | 10k resistor (keeps the MOSFET turned off Ω when no signal is present)

### Power and Ground

5V power rail
- Pi pin 2 (5V output) –> Pi pin 4 (5V output), FLIR Lepton VIN (5V), AHT20 VIN (5V power), BNO055 VIN (5V power)
3.3V power rail (from WittyPi)
- WittyPi 3V3 output –> MTDOT VDD (3.3V power)
Ground
- Pi pin 6 (GND) –> Pi pin 9 (GND), Pi pin 14 (GND), Pi pin 20 (GND), Pi pin 25 (GND), Pi pin 30 (GND), Pi pin 34 (GND), Pi pin 39 (GND), FLIR Lepton GND, WittyPi GND, MOSFET source, resistor lead 1, AHT20 GND, BNO055 GND, MTDOT GND

### I²C Bus (shared by AHT20, BNO055, FLIR Lepton)

I²C data bus (Pi GPIO 2 / SDA)
- Pi pin 3 (I²C SDA / data) –> FLIR Lepton SDA (I²C data), AHT20 SDA (I²C data), BNO055 pin 3 (silkscreen ‘SCL’)

I²C clock bus (Pi GPIO 3 / SCL)
- Pi pin 5 (I²C SCL / clock) –> FLIR Lepton SCL (I²C clock), AHT20 SCL (I²C clock), BNO055 pin 2 (silkscreen ‘SDA’)

### UART (Pi ↔ MTDOT serial communication)

Pi UART5 TX → MTDOT PA_3 (Pi sends data to MTDOT)
- Pi pin 32 (GPIO 12 / UART5 TX) –> MTDOT PA_3 (UART RX from Pi) Pi UART5 RX ← MTDOT PA_2 (Pi receives data from MTDOT)
- Pi pin 33 (GPIO 13 / UART5 RX) –> MTDOT PA_2 (UART TX to Pi)

### SPI Bus (Pi ↔ FLIR Lepton)

SPI clock to FLIR Lepton
- Pi pin 23 (GPIO 11 / SPI clock) –> FLIR Lepton SCLK (SPI clock) SPI data: Pi → FLIR Lepton
- Pi pin 19 (GPIO 10 / SPI MOSI) –> FLIR Lepton MOSI (SPI data in) SPI data: FLIR Lepton → Pi
- Pi pin 21 (GPIO 9 / SPI MISO) –> FLIR Lepton MISO (SPI data out)
Pi GPIO 8 / SPI chip select for FLIR Lepton
- Pi pin 24 (GPIO 8 / SPI chip select 0) –> FLIR Lepton CS (SPI chip select)

### FLIR Lepton additional control signals

Pi GPIO 17 → FLIR Lepton control
- Pi pin 11 (GPIO 17) –> FLIR Lepton VSYNC / control
Pi GPIO 6 → FLIR Lepton control
- Pi pin 31 (GPIO 6) –> FLIR Lepton control

### MTDOT to Pi GPIO 5 connection

Pi GPIO 5 → MTDOT PA_6
- Pi pin 29 (GPIO 5) –> MTDOT PA_6

### MTDOT wake circuit (how the radio tells the Pi to power on)

The MTDOT can wake the Raspberry Pi by signalling the WittyPi. It does this through a small NMOS switching circuit:
Signal flow: MTDOT pin 19 (PB_1) –> MOSFET gate –> MOSFET drain –> WittyPi SW pin

When the MTDOT drives PB_1 high, the MOSFET turns on, pulling the WittyPi’s SW pin to ground. The WittyPi sees this as a button press and wakes the Pi. The 10k resistor on the gate Ω keeps the MOSFET reliably off when PB_1 is idle.
MTDOT wake signal (drives MOSFET gate)
- MOSFET gate –> resistor lead 2, MTDOT PB_1 (wake signal to Pi)
WittyPi wake/shutdown signal
- WittyPi SW (shutdown/wake input) –> MOSFET drain

### Pi GPIO pins routed but not used by any component on the hat

These Pi GPIOs are connected to the GPIO header but don’t drive anything on this hat. The signal is available at the Pi but doesn’t go anywhere else.
- Pi pin 8 (GPIO 14 / UART0 TX) (no destination on this hat)
- Pi pin 10 (GPIO 15 / UART0 RX) (no destination on this hat)
- Pi pin 36 (GPIO 16) (no destination on this hat)
- Pi pin 12 (GPIO 18) (no destination on this hat)
- Pi pin 35 (GPIO 19) (no destination on this hat)
- Pi pin 38 (GPIO 20) (no destination on this hat)
- Pi pin 40 (GPIO 21) (no destination on this hat)
- Pi pin 15 (GPIO 22) (no destination on this hat)
- Pi pin 16 (GPIO 23) (no destination on this hat)
- Pi pin 18 (GPIO 24) (no destination on this hat)
- Pi pin 22 (GPIO 25) (no destination on this hat)
- Pi pin 37 (GPIO 26) (no destination on this hat)
- Pi pin 13 (GPIO 27) (no destination on this hat)
- Pi pin 7 (GPIO 4) (no destination on this hat)
- Pi pin 26 (GPIO 7 / SPI chip select 1) (no destination on this hat)

### Pi HAT ID EEPROM pins

Per the Raspberry Pi HAT specification, these pins must remain unconnected when no HAT ID EEPROM is fitted. They are correctly left alone here.
- Pi pin 27 (HAT ID SDA) (correctly left unconnected)
- Pi pin 28 (HAT ID SCL) (correctly left unconnected)

### Pins intentionally left unconnected

These pins exist on the components but are not wired to anything else. Most are unused functions on standard breakout boards.
BNO055: BNO055 RST (reset, unused); BNO055 3V (unused); BNO055 PSI (mode, unused); BNO055 PS0 (mode, unused); BNO055 ADR (address, unused); BNO055 INT (interrupt, unused)

MTDOT: MTDOT NRESET (unused); MTDOT PA_8 (unused); MTDOT PC_9 (unused); MTDOT RFU (reserved); MTDOT PA_11 (unused); MTDOT VOUT (do not connect); MTDOT GND (currently floating!); MTDOT PA_14 (unused); MTDOT PA_13 (unused); MTDOT PB_4 (unused); MTDOT PB_3 (unused); MTDOT PA_10 (unused); MTDOT PA_9 (unused); MTDOT PB_0 (unused); MTDOT PA_5 (unused); MTDOT PA_4 (unused); MTDOT PA_1 (unused); MTDOT PC_1 (unused); MTDOT NC; MTDOT PC_13 (unused); MTDOT PA_0 (unused); MTDOT PA_7 (unused)
FLIR Lepton: FLIR Lepton pin 3 (unused); FLIR Lepton pin 4 (unused); FLIR Lepton pin 6 (unused); FLIR Lepton pin 11 (unused); FLIR Lepton pin 13 (unused); FLIR Lepton pin 14 (unused); FLIR Lepton pin 16 (unused); FLIR Lepton pin 18 (unused); FLIR Lepton pin 19 (unused); FLIR Lepton pin 20 (unused)
WittyPi: WittyPi VOUT (battery, unused); WittyPi LED (unused); WittyPi ALM (unused); WittyPi CATH (unused)
Pi: Pi pin 1 (Pi 3.3V, unused); Pi pin 17 (Pi 3.3V, unused)

### Things worth checking

BNO055 SDA/SCL labels appear swapped
The schematic symbol for the BNO055 labels pin 2 as ‘SDA’ and pin 3 as ‘SCL’. But the netlist shows BNO055 pin 2 connected to the Pi’s SCL line and BNO055 pin 3 connected to the Pi’s SDA line - the opposite of what the labels suggest.
Either the schematic symbol library has the labels backwards (in which case the wiring is correct), or the SDA and SCL traces really are crossed (in which case the I²C bus won’t work). Worth verifying with a multimeter against the actual Adafruit BNO055 breakout silkscreen. MTDOT pin 12 (GND) is floating
The MTDOT has two ground pins. Pin 10 is connected to GND. Pin 12 is not connected to anything. Both should be tied to ground for the LoRa radio’s RF performance. Fix in v6.1. MOSFET wake circuit gate floats at about 1.7V
When the MTDOT is idle, its pin 19 (PB_1) sits at roughly 1.7V instead of being driven cleanly high or low. That voltage is right at the IRLB8721’s gate threshold, which makes the wake circuit’s behaviour unpredictable. The 10k pull-down resistor helps, but a higher-threshold Ω MOSFET or an active driver would be more reliable.

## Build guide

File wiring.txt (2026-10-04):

Raspberry Pi GPIO:

Pi pin 2/4 (5V) -> Lepton Breakout P2 (PWR)
             5V -> BNO0x5/AHT20 PWR

Pi pin 3 SDA -> Lepton Breakout P5
Pi pin 5 SCL -> P8

WittyPi 6 pin output

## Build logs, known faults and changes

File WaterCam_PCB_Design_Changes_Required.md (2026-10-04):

# WaterCam PCB HAT — Design Changes Required

**Prepared:** 2026-03-26  
**Last updated:** 2026-05-10  
**Board version analyzed:** WaterCam_v6.0_OFM  
**Current schematic:** WaterCam_mDot_WittyPi_AHT_BNO_Lepton.kicad_sch (v8, all schematic fixes applied)  
**Stack:** Raspberry Pi 4B → WittyPi 4 (40-pin stacking HAT) → This PCB (on top via stacking header)

---

## Issue Status Summary

| # | Issue | Priority | Status |
|---|---|---|---|
| 1 | J2 connector pinout wrong | Critical | ✅ Fixed in schematic |
| 2 | GPIO17 conflict (WittyPi SYS_UP) | Critical | ✅ Fixed — J2-P15 → GPIO24 |
| 3 | mDot UART connection | Critical | ✅ Was already correct |
| 4 | mDot antenna connection | Critical | ✅ N/A — mDot has built-in u.FL |
| 5 | IR-CUT camera GPIO circuit | High | ⏸ Deferred — circuit is external to HAT PCB |
| 6 | WittyPi CATH/VOUT unconnected | High | ⏸ Deferred — not needed for current use case |
| 7 | HAT EEPROM missing | High | ⏸ N/A — EEPROM not needed on this board |
| 8 | No decoupling capacitors | High | ⚠️ PCB layout only — caps not yet placed |
| 9 | No I2C pull-up resistors | High | ✅ Fixed in schematic — R6, R7 (4.7 kΩ) added |
| 10 | BNO055/085 ambiguity + INT/RST | Medium | ✅ Fixed — BNO055 confirmed; INT→GPIO20, RST→GPIO16 |
| 11 | Q1 MOSFET oversized | Medium | ✅ Fixed in schematic — swapped to 2N7002 SOT-23 |
| 12 | Stacking header height | Medium | ⚠️ BOM note only — verify 11–13 mm before fab |
| 13 | mDot duplicate pad "24" | Medium | ⚠️ PCB layout only — footprint edit needed |
| 14 | Q1 gate resistor missing | Medium | ✅ Fixed in schematic — R8 (100 Ω) added |
| 15 | mDot VDD decoupling | Low | ⚠️ PCB layout only — same as #8 |
| 16 | mDot nReset unconnected | Low | ✅ Fixed in schematic — R9 (10 kΩ pull-up) to 3V3 |
| 17 | Lepton PW_DWN_L unconnected | Low | ✅ Fixed — P18 tied to +3.3V |
| 18 | Board-level 3.3V rail | Low | ⏸ Deferred — J1 pin 1 now drives +3V3 net for pull-ups |

---

## Critical — Hardware Will Not Function Without These Fixes

### 1. ~~FLIR Lepton Breakout v2 (J2) Connector Pinout Is Wrong~~ — FIXED

**Problem:** The J2 connector (FLIR Lepton Breakout Board v2 host interface, 2×10 20-pin) has signals assigned to wrong pins. Almost all SPI and I2C connections are misrouted.

**FLIR Lepton Breakout v2 J2 Correct Pinout** (from FLIR document 250-0577-24):

| Pin | Signal | Direction | Raspberry Pi GPIO |
|-----|---|---|---|
| P1  | SDA | Bidirectional (I2C) | GPIO2/SDA1 (Pi pin 3) |
| P2  | VIN | Power in (3.3V–5V)  | 5V (Pi pin 2) |
| P3  | SPI_CLK | Input to Lepton | GPIO11/SPI0.SCLK (Pi pin 23) |
| P4  | SPI_CLK | (parallel/redundant) | — |
| P5  | SPI_MOSI | Input to Lepton | GPIO10/SPI0.MOSI (Pi pin 19) |
| P6  | GND | — | GND |
| P7  | GND | — | GND |
| P8  | SPI_CS | Input (active low)  | GPIO8/SPI0.CE0 (Pi pin 24) |
| P9  | — | NC | — |
| P10 | SPI_CS_L | Input (active low) | (same net as P8 or alternate CS) |
| P11 | GPIO3  | Lepton GPIO | NC or free GPIO |
| P12 | SPI_MISO | Output from Lepton | GPIO9/SPI0.MISO (Pi pin 21) |
| P13 | GPIO0  | Lepton GPIO | NC or free GPIO |
| P14 | SPI_CS | (duplicate/alt) | — |
| P15 | GPIO2  | Lepton GPIO | Use GPIO24 or GPIO25 (NOT GPIO17) |
| P16 | VPROG  | Programming voltage | NC (leave floating or connect to 3.3V) |
| P17 | RESET_L | Input (active low) | GPIO6 (Pi pin 31) — kept |
| P18 | PW_DWN_L | Input (active low) | Assign free GPIO (e.g., GPIO25) |
| P19 | SCL | Bidirectional (I2C) | GPIO3/SCL1 (Pi pin 5) |
| P20 | GPIO1  | Lepton GPIO | NC |

**Current (wrong) mapping:**
| J2 Pin | Current net | Correct net |
|---|---|---|
| P1 | GND | SDA/GPIO2 ← CRITICAL |
| P5 | SDA/GPIO2 | SPI_MOSI/GPIO10 ← CRITICAL |
| P7 | SPI_CLK/GPIO11 | GND ← CRITICAL |
| P8 | SCL/GPIO3 | SPI_CS/GPIO8 ← CRITICAL |
| P9 | SPI_MOSI/GPIO10 | NC/GND ← CRITICAL |
| P12 | SPI_MISO/GPIO9  | SPI_MISO/GPIO9 ✓ CORRECT |
| P15 | GPIO17 | GPIO24 (GPIO17 reserved for WittyPi!) |
| P19 | NC | SCL/GPIO3 ← CRITICAL |

**Action:** Rewire J2 in schematic:
- Remove GND from P1; connect P1 → GPIO2/SDA1
- Change P5 from SDA → SPI_MOSI/GPIO10
- Change P7 from SPI_CLK → GND
- Change P8 from SCL → SPI_CS/GPIO8
- Change P9 from SPI_MOSI → NC
- Keep P12 → SPI_MISO (correct)
- Change P15 from GPIO17 → GPIO24 (VSYNC or Lepton GPIO)
- Change P19 from NC → SCL/GPIO3
- Keep P17 → GPIO6 (RESET_L)

> **Note:** Verify the P2 power connection against physical board. The schematic shows P2 as an internal VCC28 (2.8V) net which may be an output; the correct host connection is VIN (5V) input. Current design has +5V → P2 which appears correct based on the breakout's power circuit topology.

### 2. ~~GPIO17 Conflict — WittyPi SYS_UP vs Lepton~~ — FIXED

**Problem:** GPIO17 is claimed by WittyPi 4. It is the SYS_UP signal that the Pi writes HIGH when running (WittyPi reads this). The current schematic also routes GPIO17 to J2-P15 (a Lepton GPIO output pin). This creates a bus conflict: Pi driving GPIO17 HIGH (SYS_UP) while Lepton may be driving J2-P15 as output → **potential damage**.

**Action:** Change J2-P15 from GPIO17 to GPIO24 (free GPIO, Pi pin 18). GPIO17 must remain exclusively for WittyPi.

### 3. mDot UART Connection ~~RESOLVED~~

**Resolution:** The Raspberry Pi uses **UART5** for the mDot connection. UART5 uses GPIO12 (TXD5, Pi pin 32) and GPIO13 (RXD5, Pi pin 33) — the pins the schematic already connects to the mDot. The original schematic was correct for UART5; the document previously misidentified these as "PWM-only" pins.

GPIO12 and GPIO13 are alternate-function pins:
- GPIO12: ALT0 = PWM0, **ALT5 = TXD5** ← UART5 TX
- GPIO13: ALT0 = PWM1, **ALT5 = RXD5** ← UART5 RX

**mDot USART2 Pins:**
- PA_2 (mDot pad 2) = USART2_TX (mDot transmits) → GPIO13/RXD5 (Pi receives) ✓
- PA_3 (mDot pad 3) = USART2_RX (mDot receives) → GPIO12/TXD5 (Pi transmits) ✓

**Current schematic (correct):**
- mDot PA_2 → GPIO13/RXD5 ✓
- mDot PA_3 → GPIO12/TXD5 ✓
- J1 GPIO14 (pin 8): no_connect ✓
- J1 GPIO15 (pin 10): no_connect ✓

**Action:** No schematic change needed for UART routing. Ensure UART5 is enabled in `/boot/config.txt` (`dtoverlay=uart5`) and the kernel serial port is `/dev/ttyAMA5`.

> **Note:** GPIO14/GPIO15 (UART0) remain free. UART0 maps to the Bluetooth controller by default on Pi 4B; no conflict with mDot on UART5.

### 4. ~~mDot Has No Antenna Connection~~ — N/A

**Resolution:** The Multitech MTDOT-915 module includes a built-in u.FL connector on the module itself. No separate antenna footprint is needed on the HAT PCB. Connect an external antenna directly to the mDot's u.FL port. Maintain a 5mm copper keepout zone on the HAT PCB in the area directly above/below the mDot module to avoid detuning the antenna.

### 5. Missing IR CUT Camera GPIO Control Circuit

**Problem:** The modified IR CUT camera requires GPIO control for its filter. No connector or control circuit exists in the current design.

**How the IR CUT control mechanism works:**

The Dorhea IR CUT camera module contains an internal IR CUT controller IC that drives the filter motor.  The controller decides which filter position to use by reading a photoresistor (LDR) voltage divider:

- LDR high resistance (dark scene) → divider node voltage high → controller switches to night mode (removes IR cut filter)
- LDR low resistance (bright scene) → divider node voltage low → controller switches to day mode (inserts IR cut filter)

The modification for Pi control removes the LDR and connects the divider node to a Pi GPIO.

**Why direct GPIO connection is unreliable:**

The GPIO is a low-impedance voltage source.  When it drives HIGH into the LDR divider node, the fixed pull-down resistor in the divider loads the pin below the Pi's logic HIGH threshold (~1.6 V).  In testing, `GPIO.input()` read 0 in both HIGH and LOW states even though the motor did move — because the camera comparator threshold is lower than the Pi's logic threshold, and the voltage swing at the node (0 V to ~1 V) was enough for the camera but not enough for the Pi to read back.  This margin is unreliable across temperature, supply voltage variation, and camera module tolerances.

**Correct PCB circuit: NPN transistor open-collector switch**

Replace the direct wire with an NPN transistor (2N3904 or BSS138 SOT-23) to present the high/low impedance the camera comparator was designed for:

```
GPIO22 ──[R1: 1 kΩ]── Base
                       Collector ── LDR node (camera connector pin)
                       Emitter  ── GND

R2: 10 kΩ from Base to GND  (ensures transistor is off when GPIO floats at boot)
```

- GPIO22 LOW → transistor off → node floats up through camera's internal pull-up → controller sees "dark" → night mode (IR cut filter removed)
- GPIO22 HIGH → transistor saturates, ~10–50 Ω collector-emitter → node pulled to GND → controller sees "bright" → day mode (IR cut filter inserted)

The transistor presents the same impedance characteristic the comparator expects, regardless of GPIO drive strength.

**Action:** Add the following to the schematic and PCB:

1. Connector J4 — 3-pin JST-PH or 2.54mm THT:
   - Pin 1: LDR node signal (to camera photoresistor pin)
   - Pin 2: GND (to camera photoresistor GND reference)
   - Pin 3: Camera 5V power (if powering camera from board; otherwise NC)

2. Transistor Q2 — 2N3904 or BSS138 (SOT-23):
   - Collector → J4 pin 1 (LDR node)
   - Emitter → GND
   - Base → R1

3. R1 = 1 kΩ (0402) — GPIO22 to Q2 base
4. R2 = 10 kΩ (0402) — Q2 base to GND (pull-down, prevents floating gate at boot)

GPIO22 (Pi pin 15) is used — one GPIO only.  GPIO27 is not needed and remains free.

---

## High Priority — Functional But Broken

### 6. WittyPi P3 Header: VOUT and CATH Unconnected

**Problem:** The WittyPi P3 header (J3) VOUT and CATH pins are floating (no_connect). Per WittyPi 4 manual, **the Raspberry Pi is powered between VOUT and CATHODE**, not between VOUT and GND. The CATH pin has a 0.05Ω sampling resistor between it and GND (for current measurement). If this board needs to draw 5V power from WittyPi's regulated output (for the mDot bulk capacitors, for example), it must connect to VOUT and CATH, not VOUT and GND.

**Key facts:**
- VOUT = +5V switched output (same as Pi GPIO header pin 2)
- CATH = the "ground" for the Pi (not the WittyPi board GND)
- GND in P3 = WittyPi board ground (power supply ground, NOT Pi ground)
- 3V3 in P3 = WittyPi internal 3.3V (powers MCU/RTC, NOT same as Pi 3.3V)
- SW/SWITCH = connects to GPIO4 AND to the physical button
- ALM = RTC alarm signal (HIGH normally, goes LOW on alarm)
- LED = LED anode (add 1K series resistor)

**Current connections:**
- J3-2 (3V3) → mDot VDD ← WRONG: this is WittyPi internal 3V3, NOT suitable for mDot
- J3-5 (SW) → Q1 Drain (MOSFET) ← Correct concept, see notes on Q1
- J3-7 (GND) → GND ← Technically correct for WittyPi board GND

**Action:**
- mDot VDD (U3 pad 1) must remain on WittyPi P3-3V3.  The mDot must stay powered when the Pi is off so it can receive an inbound LoRa wake command and assert the WittyPi SW line via Q1 to restart the Pi.  The Pi's 3.3 V GPIO rail (pins 1/17) goes off when the Pi is powered down — connecting mDot VDD there would break the remote wake path entirely.
- The problem with P3-3V3 is current, not voltage: the mDot draws up to ~127 mA peak during LoRa TX, which exceeds what the WittyPi's MCU/RTC rail is rated to supply continuously.  Resolve this with decoupling capacitors at the mDot VDD pin: C1 = 100 µF electrolytic + C2 = 100 nF ceramic, placed within 5 mm of U3 pad 1.  TX current spikes will then be sourced from the local caps rather than drawn from the WittyPi rail.
- J3-VOUT (pin 1): Connect to a test point or the HAT's 5V power input rail
- J3-CATH (pin 6): Connect to board GND reference (monitoring point)
- J3-ALM (pin 4): Connect to a free Pi GPIO if alarm detection is needed (e.g., GPIO26)
- J3-LED (pin 3): Leave NC or connect to GPIO via 1K resistor for status LED

### 7. ~~HAT EEPROM Missing~~ — N/A

**Decision:** EEPROM not needed on this board. HAT EEPROM is optional per Pi spec; required only for automatic device-tree overlay loading by the Pi firmware. This board loads its overlays manually via `/boot/firmware/config.txt`. GPIO0/GPIO1 (ID_SDA/ID_SCL) remain unconnected. U4, R4, R5 should be removed from schematic.

### 8. No Decoupling Capacitors

**Problem:** No bypass/decoupling capacitors exist anywhere on the board. This is particularly critical for the mDot (LoRa TX generates large current spikes up to 600mA peak) and the Lepton breakout (150mA switching).

**Action:** Add at minimum:
- C1 = 100µF electrolytic (6.3V or 10V) near mDot VDD → GND
- C2 = 100nF ceramic (0402 or 0603) near mDot VDD → GND
- C3 = 100nF ceramic near AHT20 VDD → GND
- C4 = 10µF ceramic near AHT20 VDD → GND
- C5 = 100nF ceramic near BNO055/BNO085 VIN → GND
- C6 = 100nF ceramic near J2-P2 (Lepton VIN) → GND
- Place all caps as close to the device VDD/GND pins as possible

### ~~9. No I2C Pull-Up Resistors on Board~~ — FIXED

**Problem:** The I2C bus (GPIO2/SDA1, GPIO3/SCL1) had no pull-up resistors. The Adafruit breakout boards include their own pull-ups, but multiple boards in parallel weaken the effective pull-up. The Lepton CCI interface also requires stable pull-ups to reliably acknowledge at 0x2A.

**Resolution:** R6 (4.7 kΩ, 0402) from SDA1 to +3V3 and R7 (4.7 kΩ, 0402) from SCL1 to +3V3 added to schematic. Both connect via net labels to the GPIO2/SDA1 and GPIO3/SCL1 nets respectively, with +3V3 symbols at pin 2. J1 pin 1 (Pi 3.3V output) is now connected to the +3V3 power net (no_connect removed). The `power:+3V3` lib_symbol was added to the schematic's inline symbol library. R6 is at schematic position (25.4, 20.32); R7 at (30.48, 20.32), placed above J1.

---

## Medium Priority — Improvements

### 10. ~~BNO055 vs BNO085 Ambiguity~~ — FIXED

**Problem:** The schematic and PCB show the Adafruit BNO055 STEMMA QT breakout (U2), but the project description mentions BNO085. These are different physically (different Adafruit board ID, different I2C register sets).

**Resolution:** BNO055 Adafruit STEMMA QT breakout (U2) is confirmed. INT connected to GPIO20 (pin 38); RST connected to GPIO16 (pin 36). I2C address 0x28 (ADDR=GND default on breakout). GPIO21 is reserved for IR-CUT filter and was not used for RST.

### ~~11. MOSFET Q1 Choice Is Inappropriate~~ — FIXED

**Problem:** Q1 was an IRLB8721PBF, a 30V/62A power MOSFET in TO-252 package — massive overkill for a logic-level signal switch pulling the WittyPi SW line LOW.

**Resolution:** Q1 replaced in schematic with 2N7002 (60V/300mA, SOT-23). The mDot PB_1 3.3V drive is sufficient: Vgs(th) for 2N7002 is 1.0–2.5V. Footprint changed to `Package_TO_SOT_SMD:SOT-23`. R3 (10kΩ pull-down at gate) retained. R8 (100Ω series gate resistor) added simultaneously — see issue #14.

### 12. WittyPi 40-Pin Stacking Header Required

**Problem:** The board occupies the Pi's 40-pin GPIO header. The WittyPi 4 also needs the Pi's 40-pin header (it stacks on top). For a Pi → WittyPi → This HAT stack to work, this PCB needs both:
- A female 2×20 header (socket) on the BOTTOM to mate with WittyPi's male header
- A male 2×20 header (pins) on the TOP if any further stacking is needed, OR all connections terminate here

The current design uses a single 2×20 header (J1) with `MODULE_RASPBERRY_PI_4B_4GB` footprint on B.Cu. This is designed as a direct-to-Pi connection, not a WittyPi stacking connection.

**Action:**
- J1 should be a tall stacking female socket (e.g., 2×20, 11mm or 13mm height) to mate over the WittyPi's protruding pins
- Verify standoff heights: WittyPi sits on Pi at ~19mm height; this HAT needs ~5mm clearance above WittyPi components
- Consider using 2×20 stackable header (GPIO female-bottom, pins-top) if further stacking needed

### 13. Footprint Error — Duplicate Pad "24" on mDot

**Problem:** The mDot MTDOT footprint has two pads both numbered "24" at different positions with different nets. This is a footprint error that may cause manufacturing issues.

**Action:** Correct the MTDOT footprint — verify against the mDot physical dimensions. The mDot has 20 castellated pads (10 each side) plus bottom RF pad and GND pad. Pads should be numbered 1–20 plus RF/GND pads with unique numbers.

### ~~14. MOSFET Q1 Gate Resistor Missing~~ — FIXED

**Problem:** mDot PB_1 drove Q1 gate directly. The LoRa module GPIO transitions can excite gate-source capacitance (Ciss ≈ 50–100 pF on 2N7002), causing ringing that may produce spurious switching.

**Resolution:** R8 (100 Ω, 0402) added in series between mDot PB_1 and Q1 gate. R3 (10 kΩ pull-down) connects on the gate side of R8, providing DC bias when mDot is unpowered. Topology: mDot PB_1 → R8 → Q1 gate; R3 from gate to GND.

---

## Low Priority — Nice to Have

### 15. mDot Power Supply Decoupling

The mDot requires 100µF bulk + 100nF bypass at VDD for reliable LoRa operation. The mDot VDD connects to J3-3V3 (WittyPi internal 3V3), which is the correct always-on power domain (see item 6). Add the decoupling capacitors within 5mm of the mDot VDD pin so that LoRa TX current spikes are sourced locally rather than drawn from the WittyPi MCU/RTC rail.

### ~~16. mDot nReset Connection~~ — FIXED

**Problem:** mDot NRESET (active-low, pad 5) was no_connect. A floating NRESET can cause spurious resets from noise.

**Resolution:** R9 (10 kΩ, 0402) pull-up added from NRESET to WittyPi J3-3V3 (always-on 3.3V — same supply domain as mDot VDD). The pull-up must use the always-on rail, not Pi 3.3V: if Pi 3.3V were used, NRESET would assert LOW during Pi shutdown and hold the mDot in reset, breaking the remote-wake path. Software reset control was not added; GPIO26 remains free.

### 17. ~~Lepton PWREN Control~~ — FIXED

P18 (PW_DWN_L) is tied directly to +3.3V in the schematic (Fix 5). The Lepton is always powered. No software power-down is used in the current design. If software power control is needed in future, replace the direct 3.3V tie with a GPIO via a 10kΩ pull-up.

### 18. Board-Level 3.3V Rail

Currently the board has no explicit 3.3V rail from the Pi. All sensors operating at 3.3V rely on their own breakout board regulators accepting 5V input. Consider adding a small 3.3V LDO (e.g., MCP1700-3302E) powered from the Pi's 5V rail to provide a clean local 3.3V for the mDot and pull-up resistors.

---

## I2C Address Map (No Conflicts)

### I2C1 bus (GPIO2/GPIO3) — shared

| Device | Address | Notes |
|---|---|---|
| FLIR Lepton CCI | 0x2A | Fixed |
| AHT20 | 0x38 | Fixed |
| BNO055 (U2) | 0x28 | ADDR=GND (breakout default); solder jumper → 0x29 |
| WittyPi LM75B | 0x48 | On WittyPi board |
| WittyPi PCF85063A RTC | 0x51 | On WittyPi board |

### I2C0 bus (GPIO0/GPIO1)

Not used. GPIO0/GPIO1 are unconnected (no EEPROM fitted).

No address conflicts in default configuration.

---

## GPIO Allocation (Current — v7 schematic)

See `PIN_MAP.md` for the authoritative and complete pin table. Summary of assigned pins:

| GPIO | Pi Pin | Assigned To | Notes |
|---|---|---|---|
| GPIO0 / ID_SDA | 27 | NC | No EEPROM fitted |
| GPIO1 / ID_SCL | 28 | NC | No EEPROM fitted |
| GPIO2 / SDA1 | 3 | I2C1 SDA (shared bus) | Lepton CCI P1, BNO055, AHT20 |
| GPIO3 / SCL1 | 5 | I2C1 SCL (shared bus) | Lepton CCI P19, BNO055, AHT20 |
| GPIO4 | 7 | ⛔ WittyPi MCU | Reserved — do not use |
| GPIO5 | 29 | mDot PA_6 + manual button | Pi drives HIGH when running |
| GPIO6 | 31 | Lepton RESET_L (J2-P17) | Active-low; pulse LOW to reset |
| GPIO8 / CE0 | 24 | Lepton SPI CS (J2-P8) | SPI0.CE0 |
| GPIO9 / MISO | 21 | Lepton SPI MISO (J2-P12) | SPI0.MISO |
| GPIO10 / MOSI | 19 | Lepton SPI MOSI (J2-P5) | SPI0.MOSI |
| GPIO11 / SCLK | 23 | Lepton SPI CLK (J2-P3) | SPI0.SCLK |
| GPIO12 / TXD5 | 32 | mDot PA_3 (mDot RX) | UART5 TX; dtoverlay=uart5 |
| GPIO13 / RXD5 | 33 | mDot PA_2 (mDot TX) | UART5 RX |
| GPIO16 | 36 | BNO055 RST | Active-low; hold HIGH at boot |
| GPIO17 | 11 | ⛔ WittyPi SYS_UP | Reserved — never drive LOW |
| GPIO20 | 38 | BNO055 INT | Active-low output; configure pull-up |
| GPIO21 | 40 | IR-CUT filter (external) | External circuit; not on HAT PCB |
| GPIO24 | 18 | Lepton VSYNC (J2-P15) | Lepton GPIO2 output |
| Free | 12,13,15,16,22,25,26,29,35,37 | — | Available for future use |

---

## PCB Layout Notes

- **mDot antenna keepout:** 5mm zone around u.FL connector, no copper pour
- **AHT20 placement:** Keep away from mDot (RF heat), Q1, and Lepton
- **BNO055/085:** Mount on flat plane; no vibration-inducing mounting near sensor
- **Decoupling caps:** Place within 5mm of each device's VDD pin
- **I2C trace length:** Keep SDA/SCL traces short (< 100mm) and matched
- **Lepton J2 connector:** Ensure the 2×10 header footprint matches the Breakout v2 physical connector orientation (verify pin 1 marker before sending to fab)
- **Stack height:** Confirm M2.5 standoff heights accommodate WittyPi (19mm) + clearance

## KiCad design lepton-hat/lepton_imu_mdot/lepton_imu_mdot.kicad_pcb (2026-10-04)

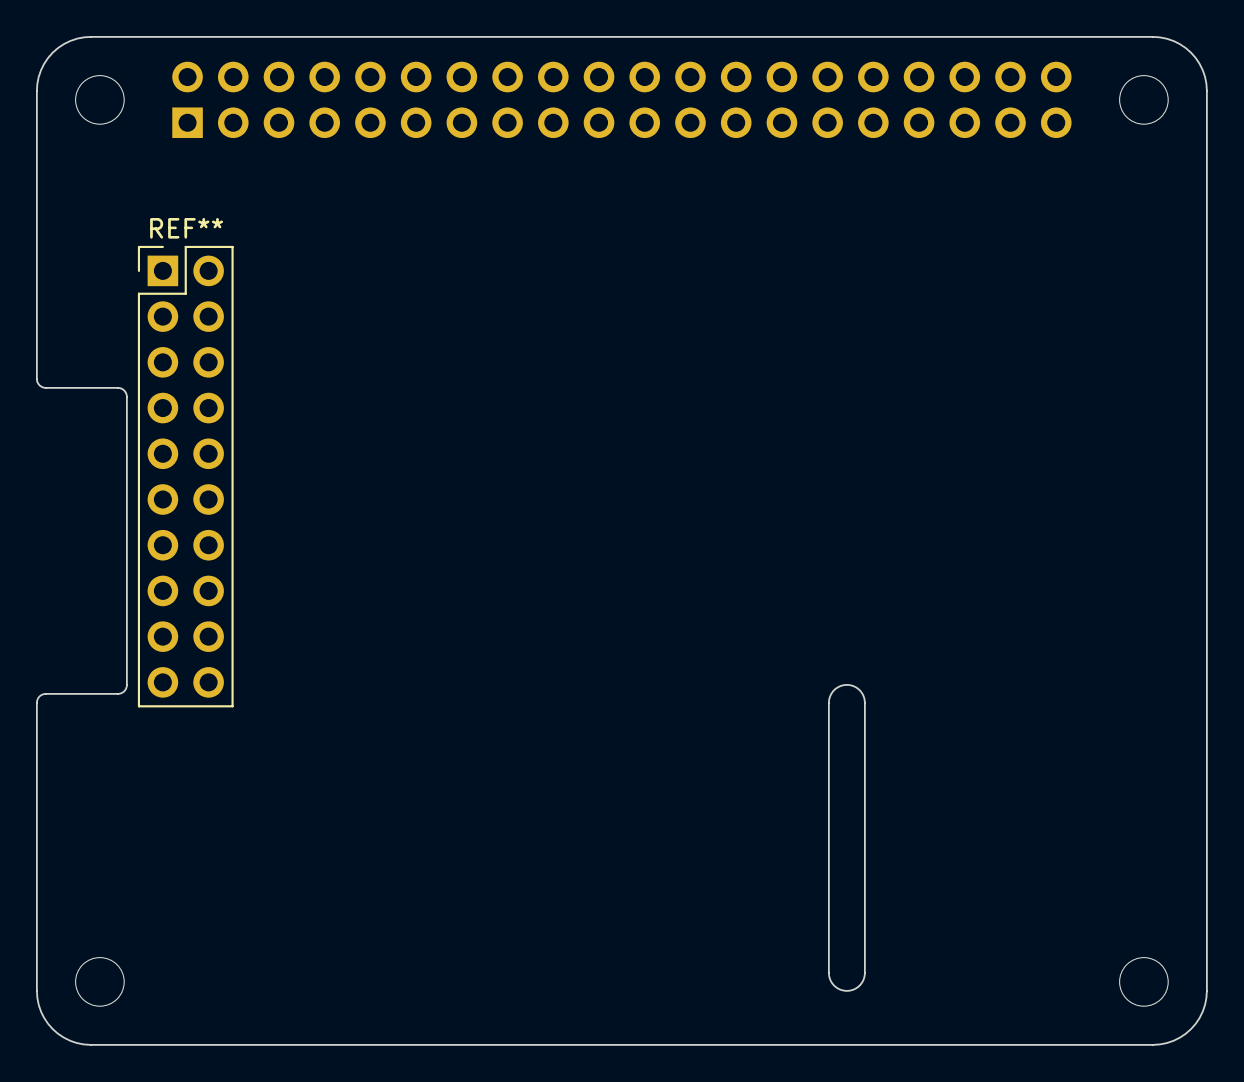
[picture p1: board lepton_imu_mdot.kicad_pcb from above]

Board: 2 copper layers, 65.0 x 56.0 mm, 5 parts (1 on the bottom side), 3 nets, no tracks yet.

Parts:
J1: GPIO; PinSocket_2x20_P2.54mm_Vertical
MH1, MH2, MH3, MH4: MountingHole_2.7mm_M2.5

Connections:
+3V3: J1.1, J1.17
+5V: J1.2, J1.4
GND: J1.6, J1.9, J1.14, J1.20, J1.25, J1.30, J1.34, J1.39

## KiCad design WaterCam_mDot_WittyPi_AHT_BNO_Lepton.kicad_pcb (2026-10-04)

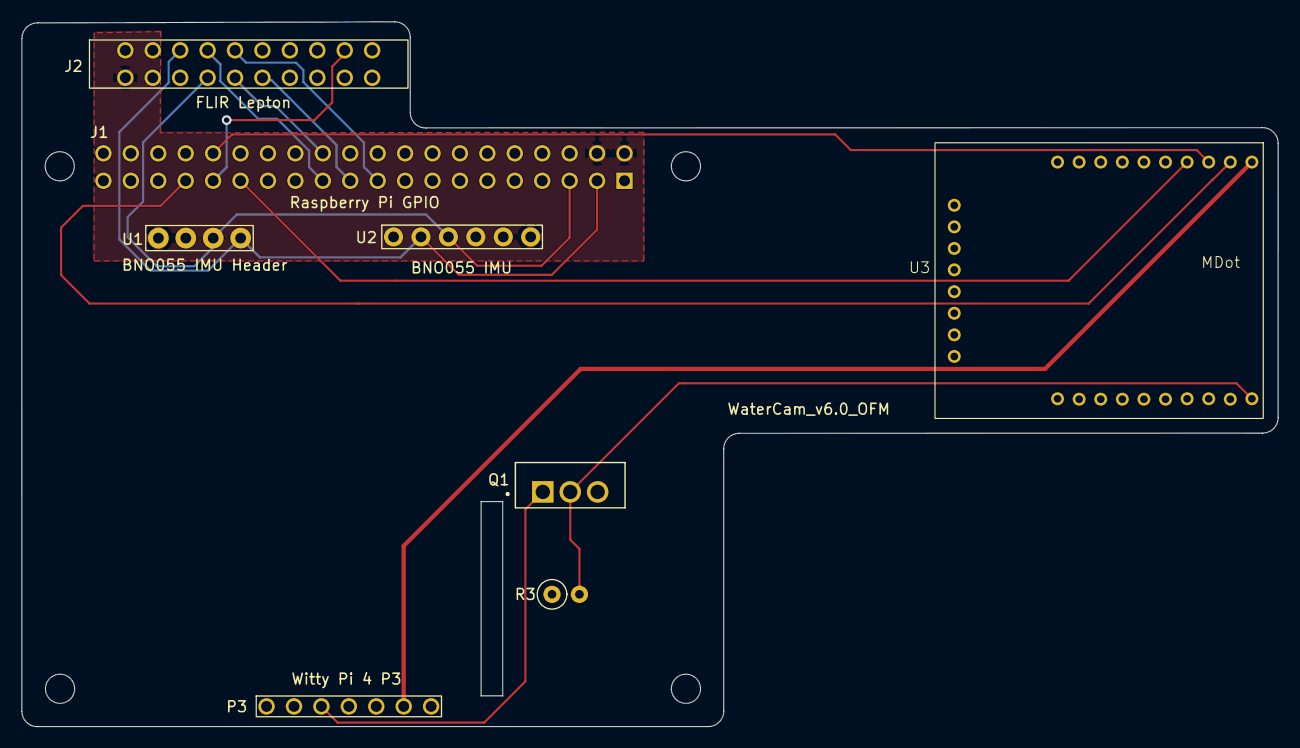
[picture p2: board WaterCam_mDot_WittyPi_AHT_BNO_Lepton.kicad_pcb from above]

Board: 2 copper layers, 116.3 x 65.3 mm, 8 parts (1 on the bottom side), 15 nets.

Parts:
J1: GPIO; MODULE_RASPBERRY_PI_4B_4GB
J2: FLIR Lepton; FLIR Lepton Breakout Board (Vertical)
P3: Witty Pi 4 P3; WittyPi4_Simple
Q1: NMOS; TO254P1067X483X2057-3
R3: 10kΩ Resistor; R_Axial_DIN0207_L6.3mm_D2.5mm_P2.54mm_Vertical
U1: ATH20; AHT20 Breakout Board
U2: BNO055 IMU; BNO-055 Breakout
U3: MDOT; MTDOT

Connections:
+5V: J1.2, J1.4, J2.2, U1.1 (VIN), U2.6 (VIN)
/GPIO2/SDA1: J1.3, J2.5, U1.4 (SDA), U2.2 (SDA)
/GPIO3/SCL1: J1.5, J2.8, U1.3 (SCL), U2.3 (SCL)
/GPIO5: J1.29, U3.4 (PA_6)
/GPIO6: J1.31, J2.17
/GPIO8/SPI0.CE0: J1.24, J2.10
/GPIO9/SPI0.MISO: J1.21, J2.12
/GPIO10/SPI0.MOSI: J1.19, J2.9
/GPIO11/SPI0.SCLK: J1.23, J2.7
/GPIO12/PWM0: J1.32, U3.3 (PA_3)
/GPIO13/PWM1: J1.33, U3.2 (PA_2)
GND: J1.6, J1.9, J1.14, J1.20, J1.25, J1.30, J1.34, J1.39, J2.1, P3.7 (GND), Q1.3 (S), R3.1, U1.2 (GND), U2.4 (GND), U3.10 (GND)
unnamed: P3.2 (3V3), U3.1 (VDD)
unnamed: P3.5 (SW), Q1.1 (D)
unnamed: Q1.2 (G), R3.2, U3.19 (PB_1)

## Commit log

2026-04-07 Correct schematic wiring and add missing components for WaterCam HAT
    Fixes applied to WaterCam_mDot_WittyPi_AHT_BNO_Lepton.kicad_sch to match
    the SU-WaterCam software wiring and Raspberry Pi HAT specification.
    Fix 1 — mDot UART5 wiring:
    - mDot PA_2 (TX) → GPIO13/RXD5 (UART5 RX), Pi pin 33
    - mDot PA_3 (RX) → GPIO12/TXD5 (UART5 TX), Pi pin 32
    - Uses /dev/ttyAMA5, dtoverlay=uart5
    Fix 2 — GPIO17 conflict resolved:
    - Removed erroneous bridge from J2-P15 to GPIO17 (WittyPi-reserved pin)
    - J2-P15 (Lepton VSYNC/GPIO2) now correctly routed to GPIO24 (Pi pin 18)
    Fix 3 — Lepton Breakout Board v2 J2 connector pinout:
    - P1: SDA (I2C CCI), P3: SPI CLK, P5: SPI MOSI, P8: SPI CS
    - P12: SPI MISO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
    [WaterCam_mDot_WittyPi_AHT_BNO_Lepton.kicad_sch]
2026-04-16 Correct mDot power supply recommendation in Item 6 and Item 15
    Item 6 Action previously said to move mDot VDD from WittyPi P3-3V3 to
    the Pi's 3.3 V GPIO rail (pins 1/17). This is incorrect: the Pi's 3.3 V
    rail is switched off when the Pi is powered down, which would cut power
    to the mDot and break the remote LoRa wake path.
    The mDot must remain powered when the Pi is off so it can receive an
    inbound LoRa wake command and pull the WittyPi SW line low via Q1 to
    restart the system. WittyPi P3-3V3 is the correct domain — it is
    always-on whenever the battery is connected.
    The real problem with P3-3V3 is current capacity during LoRa TX
    (~127 mA peak). The correct fix is decoupling capacitors a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
2026-04-16 Rewrite issue #5: IR-CUT control circuit with correct transistor design
    The previous description assumed relay or H-bridge motor drive, which is
    incorrect. The Dorhea IR-CUT camera has an internal controller IC that drives
    the filter motor itself; it determines filter position by reading a photoresistor
    (LDR) voltage divider. The Pi controls the filter by replacing the LDR with a
    GPIO connection.
    Direct GPIO connection to the LDR node works in practice (filter moves audibly
    and photos show a colour change) but is unreliable because:
    - The Pi GPIO is a low-impedance voltage source; the circuit was designed for
    a variable resistor.
    - The LDR divider's pull-down resistor loads the GPIO pin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
2026-10-04 Fix GPIO17, MASTER_CLK, WittyPi SW short, Q1 mis-pinning; OSHPark rules
    Rebased onto main after #1 (schematic corrections). The schematic and board
    are this commit's versions: they build on #1's corrections and deliberately
    drop U4/R4/R5 (HAT EEPROM not needed; overlays load from config.txt) and J4
    (the IR-cut circuit is deferred as external to the HAT), as recorded in
    WaterCam_PCB_Design_Changes_Required.md.
    Left out of the public repo: KiCad auto-backup zips, autosave/lock/-bak
    files, per-user .kicad_prl and .history, and the vendor datasheets and
    manuals (References/README.md lists where to get them). .gitignore keeps
    them out.
    [Adafruit AHT20 Temperature & Humidity.sch, Adafruit BNO055.sch, WaterCam_mDot_WittyPi_AHT_BNO_Lepton.kicad_pcb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]
2026-10-23 Plan a Pi-controlled mDot reset (Q2 on GPIO26), a debug UART header and a series resistor on the mDot's TX
2026-10-23 Plan powering the mDot from the battery's always-on 5 V instead of the Witty Pi's 3V3
2026-10-23 mDot reset and supply plan: match design change 20 (GPIO25), and explain the direct 5 V feed

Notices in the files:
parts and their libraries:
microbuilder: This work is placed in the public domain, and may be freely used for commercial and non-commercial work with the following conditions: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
